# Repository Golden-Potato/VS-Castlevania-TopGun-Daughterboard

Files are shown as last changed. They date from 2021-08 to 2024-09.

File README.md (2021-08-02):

# VS-Castlevania-TopGun-Daughterboard
https://github.com/Golden-Potato/VS-Castlevania-TopGun-Daughterboard

KiCad PCB files to create a reproduction VS Castlevania / VS Topgun daughterboard.  Have it made by your preferred PCB fab. I use http://aisler.net

This design has one minor improvement to avoid bus conflicts that were present on the original Konami design.

The bank switching scheme Konami implemented in the original NES version of Castlevania to address a 128k ROM was dubbed UNROM by the NES emulation community.
https://wiki.nesdev.com/w/index.php/UxROM
It suffered from data bus conflicts during bank switching as the CPU will write data to the bus while the ROM is still writing data to the bus.  Although this conflict was easy to avoid from a hardware standpoint, these game cartridges were to be mass produced, and it was imperative to have as small of a chip count as possible.  Rather than add another IC, Konami got around the conflict by storing the same data in ROM at the addresses being written to by the CPU as the data the CPU was trying to write.  This means that while the CPU and ROM were writing data to the bus at the same time, it was the same data.

This works fine unless the ROM becomes corrupt which can easily happen to the arcade version if programmed on a UV erasable EPROM.  If the data from the ROM and the data being written by the CPU differed, there is a risk of overloading the CPU's data port.

Comparing the original cartridge design with the schematic for VS Topgun daughterboard (located in the manual), it's apparent Konami recycled their design for bank switching the ROM with the exception of some minor changes required for the differences in hardware between the VS system and the NES.  One of the additional ICs present on the VS daughterboard is a quad 2-input NAND gate, and not all of the instances of the IC were used.  This design uses one additional instance of the NAND gate as an inverter to feed the ROM IC's /OE from the CPU's R/W pin which prevents the ROM from writing to the bus when the CPU is writing.

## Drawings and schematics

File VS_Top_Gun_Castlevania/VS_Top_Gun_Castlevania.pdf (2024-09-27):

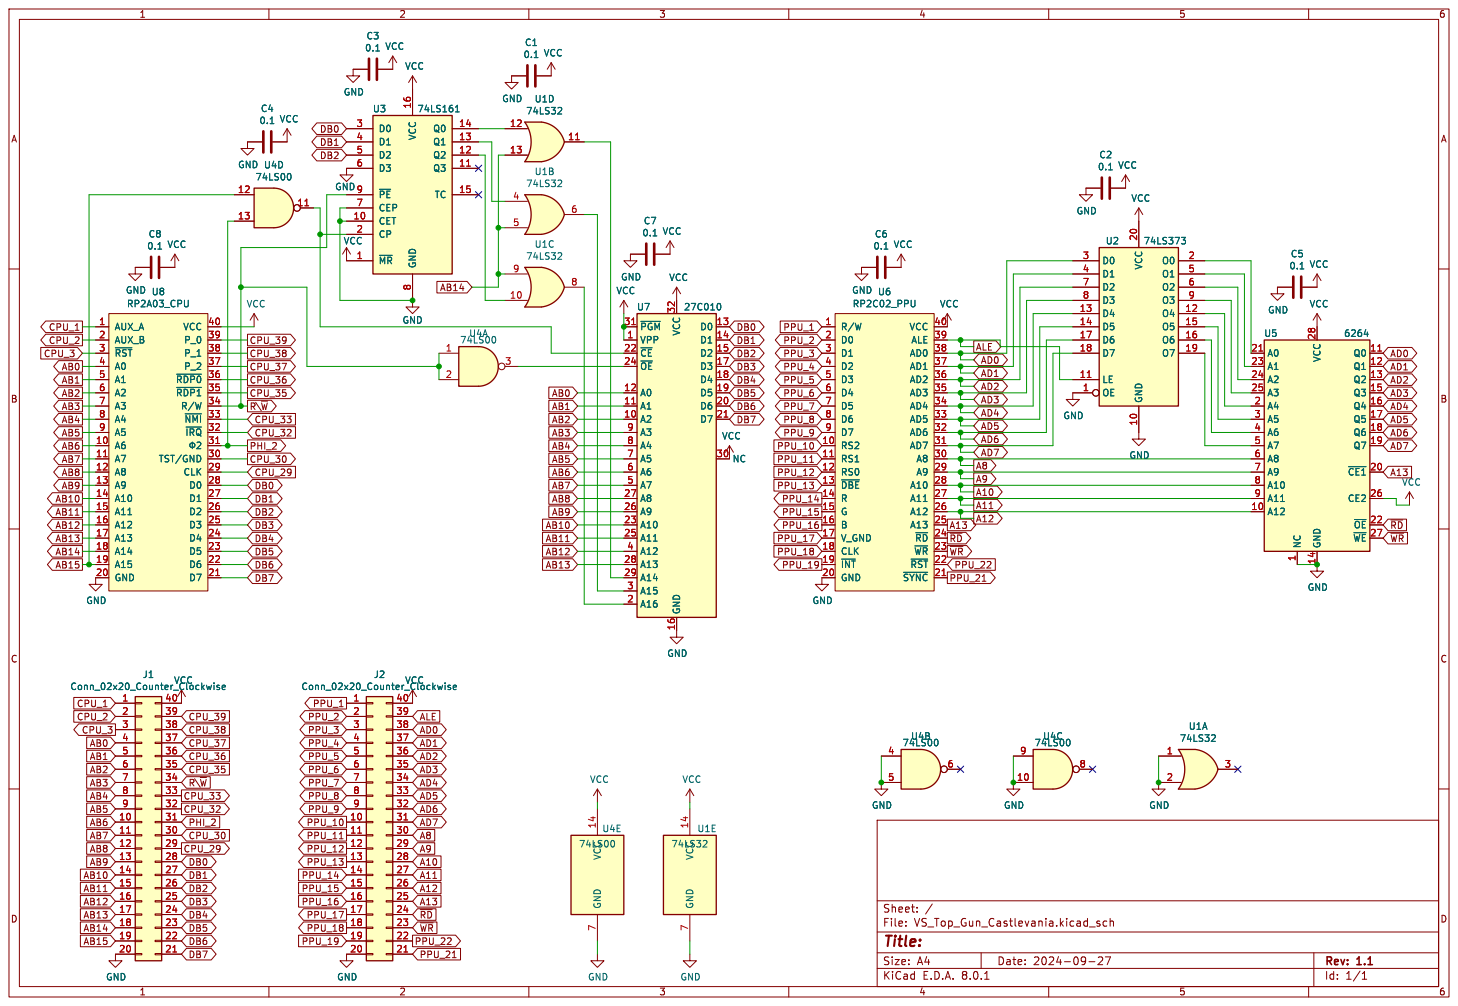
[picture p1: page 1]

1 A12 10 Q0 11 Q1 12 Q2 13 Q3 15 Q4 16 Q5 17 Q6 18 Q7 19 A4 2 ~{CE1}20 A0 21 ~{OE} 22 A1 23 A2 24 A3 25 CE2 26 ~{WE} 27 A5 3 A6 4 A7 5 A8 6 A9 7 A10 8 A11 9 U5 6264 GND GND VCC

VCC GND 14 VCC 28 NC

Id: 1/1 Title: File: VS_Top_Gun_Castlevania.kicad_sch Sheet: /

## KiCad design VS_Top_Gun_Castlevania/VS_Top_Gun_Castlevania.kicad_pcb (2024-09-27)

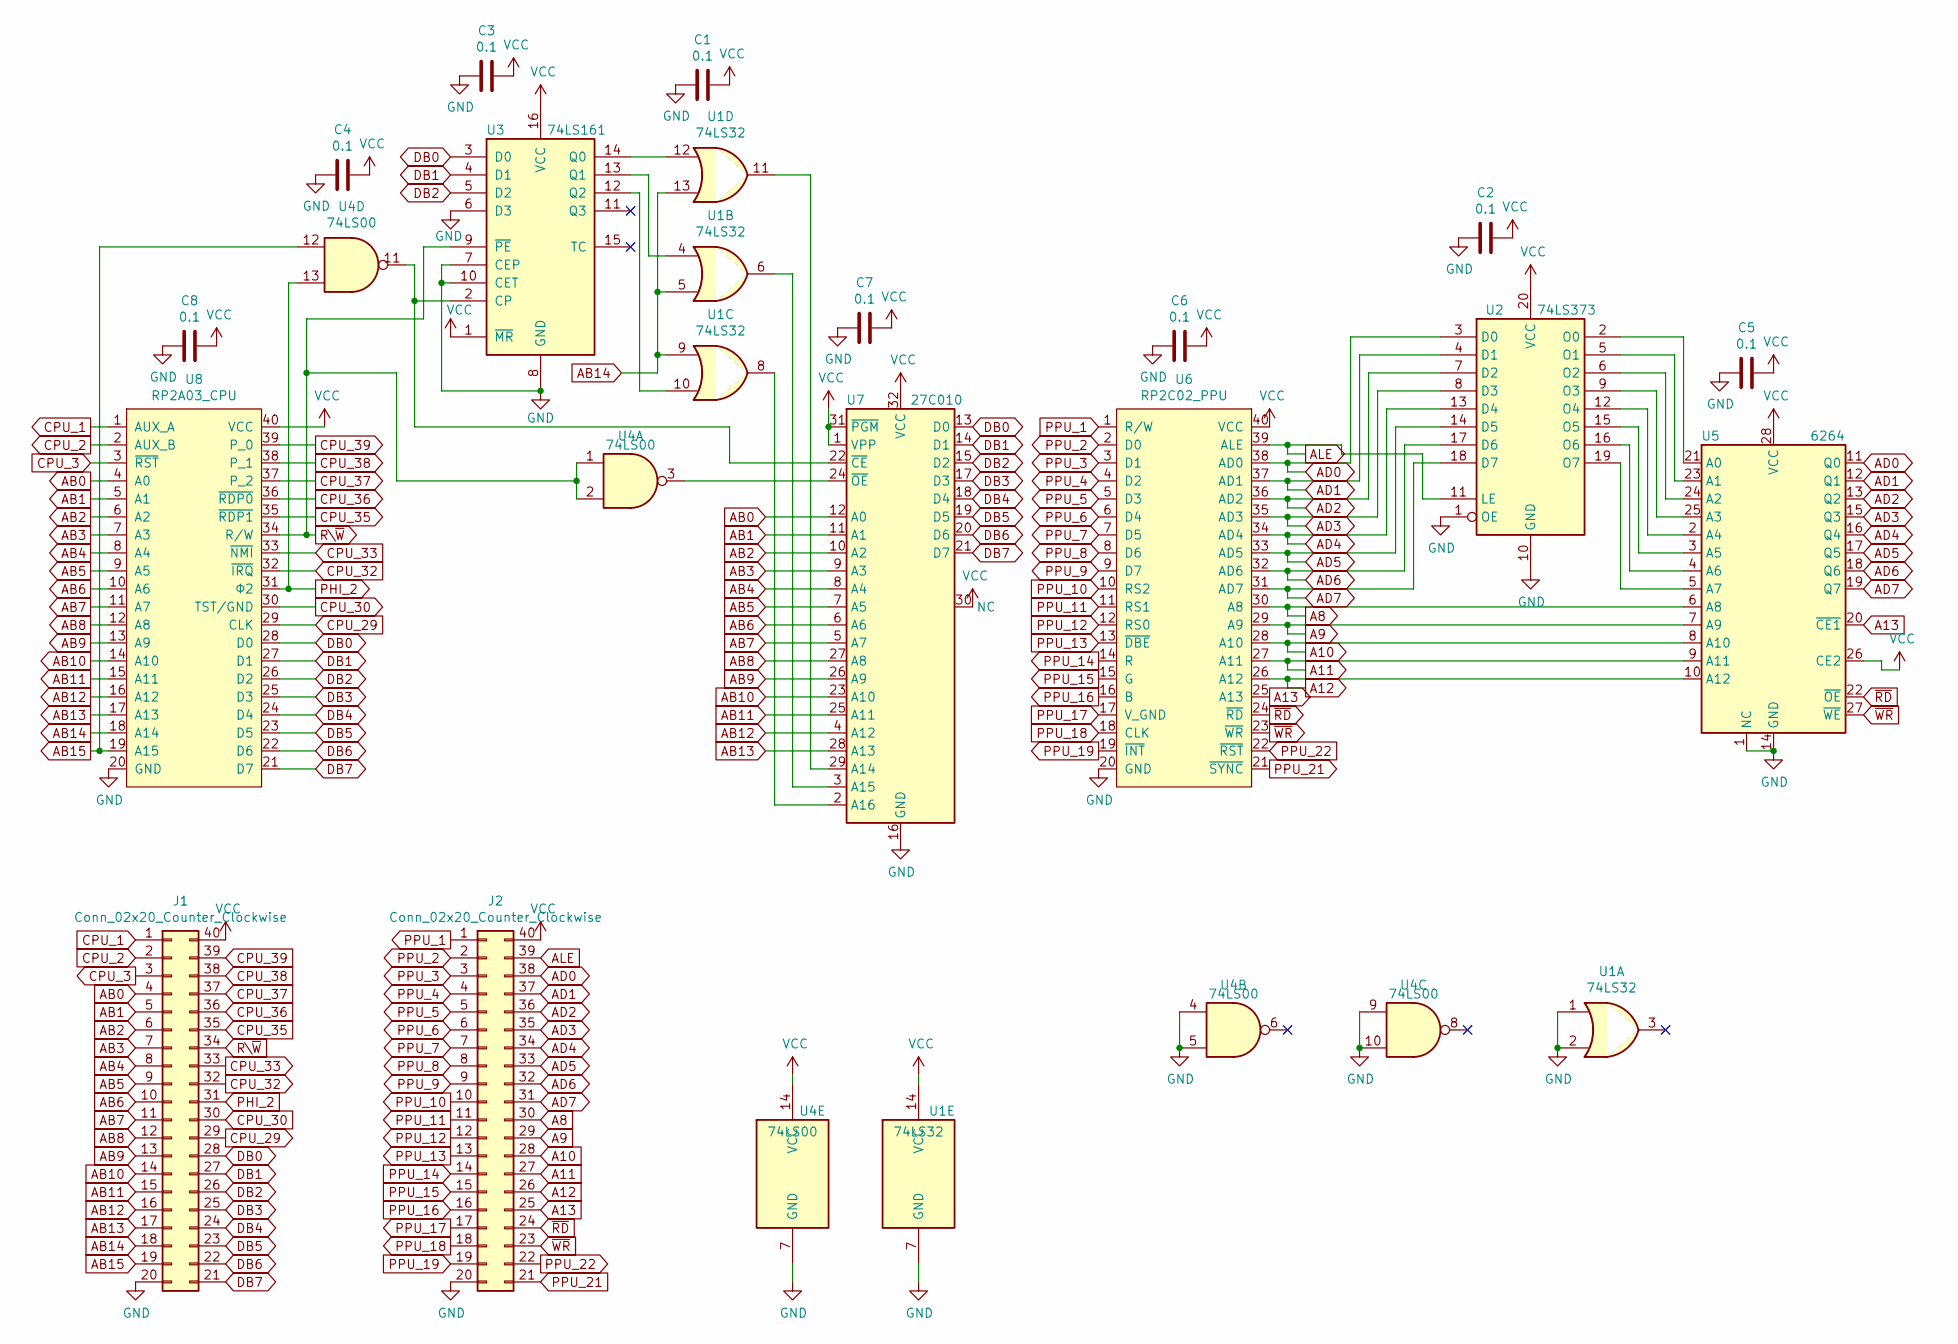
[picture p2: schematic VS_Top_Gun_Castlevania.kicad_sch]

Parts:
C1, C2, C3, C4, C5, C6, C7, C8: 0.1; C_Disc_D12.5mm_W5.0mm_P7.50mm
J1, J2: Conn_02x20_Counter_Clockwise; DIP-40_W15.24mm_Socket
U1: 74LS32; DIP-14_W7.62mm_Socket
U2: 74LS373; DIP-20_W7.62mm_Socket
U3: 74LS161; DIP-16_W7.62mm_Socket
U4: 74LS00; DIP-14_W7.62mm_Socket
U5: 6264; DIP-28_W15.24mm_Socket
U6: RP2C02_PPU; DIP-40_W15.24mm_Socket
U7: 27C010; DIP-32_W15.24mm_Socket
U8: RP2A03_CPU; DIP-40_W15.24mm_Socket

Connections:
A8: J2.30, U5.6 (A8), U6.30 (A8)
A9: J2.29, U5.7 (A9), U6.29 (A9)
A10: J2.28, U5.8 (A10), U6.28 (A10)
A11: J2.27, U5.9 (A11), U6.27 (A11)
A12: J2.26, U5.10 (A12), U6.26 (A12)
A13: J2.25, U5.20 (~CE1), U6.25 (A13)
AB0: J1.4, U7.12 (A0), U8.4 (A0)
AB1: J1.5, U7.11 (A1), U8.5 (A1)
AB2: J1.6, U7.10 (A2), U8.6 (A2)
AB3: J1.7, U7.9 (A3), U8.7 (A3)
AB4: J1.8, U7.8 (A4), U8.8 (A4)
AB5: J1.9, U7.7 (A5), U8.9 (A5)
AB6: J1.10, U7.6 (A6), U8.10 (A6)
AB7: J1.11, U7.5 (A7), U8.11 (A7)
AB8: J1.12, U7.27 (A8), U8.12 (A8)
AB9: J1.13, U7.26 (A9), U8.13 (A9)
AB10: J1.14, U7.23 (A10), U8.14 (A10)
AB11: J1.15, U7.25 (A11), U8.15 (A11)
AB12: J1.16, U7.4 (A12), U8.16 (A12)
AB13: J1.17, U7.28 (A13), U8.17 (A13)
AB14: J1.18, U1.5, U1.9, U1.13, U8.18 (A14)
AB15: J1.19, U4.12, U8.19 (A15)
AD0: J2.38, U2.3 (D0), U5.11 (Q0), U6.38 (AD0)
AD1: J2.37, U2.4 (D1), U5.12 (Q1), U6.37 (AD1)
AD2: J2.36, U2.7 (D2), U5.13 (Q2), U6.36 (AD2)
AD3: J2.35, U2.8 (D3), U5.15 (Q3), U6.35 (AD3)
AD4: J2.34, U2.13 (D4), U5.16 (Q4), U6.34 (AD4)
AD5: J2.33, U2.14 (D5), U5.17 (Q5), U6.33 (AD5)
AD6: J2.32, U2.17 (D6), U5.18 (Q6), U6.32 (AD6)
AD7: J2.31, U2.18 (D7), U5.19 (Q7), U6.31 (AD7)
ALE: J2.39, U2.11 (LE), U6.39 (ALE)
CPU_1: J1.1, U8.1 (AUX_A)
CPU_2: J1.2, U8.2 (AUX_B)
CPU_3: J1.3, U8.3 (~RST)
CPU_29: J1.29, U8.29 (CLK)
CPU_30: J1.30, U8.30 (TST/GND)
CPU_32: J1.32, U8.32 (~IRQ)
CPU_33: J1.33, U8.33 (~NMI)
CPU_35: J1.35, U8.35 (~RDP1)
CPU_36: J1.36, U8.36 (~RDP0)
CPU_37: J1.37, U8.37 (P_2)
CPU_38: J1.38, U8.38 (P_1)
CPU_39: J1.39, U8.39 (P_0)
DB0: J1.28, U3.3 (D0), U7.13 (D0), U8.28 (D0)
DB1: J1.27, U3.4 (D1), U7.14 (D1), U8.27 (D1)
DB2: J1.26, U3.5 (D2), U7.15 (D2), U8.26 (D2)
DB3: J1.25, U7.17 (D3), U8.25 (D3)
DB4: J1.24, U7.18 (D4), U8.24 (D4)
DB5: J1.23, U7.19 (D5), U8.23 (D5)
DB6: J1.22, U7.20 (D6), U8.22 (D6)
DB7: J1.21, U7.21 (D7), U8.21 (D7)
GND: C1.1, C2.1, C3.1, C4.1, C5.1, C6.1, C7.1, C8.1, J1.20, J2.20, U1.1, U1.2, U1.7 (GND), U2.1 (OE), U2.10 (GND), U3.6 (D3), U3.7 (CEP), U3.8 (GND), U3.10 (CET), U4.4, U4.5, U4.7 (GND), U4.9, U4.10, U5.1 (NC), U5.14 (GND), U6.20 (GND), U7.16 (GND), U8.20 (GND)
unnamed: U2.2 (O0), U5.21 (A0)
unnamed: U2.5 (O1), U5.23 (A1)
unnamed: U2.6 (O2), U5.24 (A2)
unnamed: U2.9 (O3), U5.25 (A3)
unnamed: U2.12 (O4), U5.2 (A4)
unnamed: U2.15 (O5), U5.3 (A5)
unnamed: U2.16 (O6), U5.4 (A6)
unnamed: U2.19 (O7), U5.5 (A7)
unnamed: U3.2 (CP), U4.11, U7.22 (~CE)
unnamed: U1.12, U3.14 (Q0)
unnamed: U1.4, U3.13 (Q1)
unnamed: U1.10, U3.12 (Q2)
unnamed: U1.11, U7.29 (A14)
unnamed: U1.6, U7.3 (A15)
unnamed: U1.8, U7.2 (A16)
unnamed: U4.3, U7.24 (~OE)
PHI_2: J1.31, U4.13, U8.31 (Φ2)
PPU_1: J2.1, U6.1 (R/W)
PPU_2: J2.2, U6.2 (D0)
PPU_3: J2.3, U6.3 (D1)
PPU_4: J2.4, U6.4 (D2)
PPU_5: J2.5, U6.5 (D3)
PPU_6: J2.6, U6.6 (D4)
PPU_7: J2.7, U6.7 (D5)
PPU_8: J2.8, U6.8 (D6)
PPU_9: J2.9, U6.9 (D7)
PPU_10: J2.10, U6.10 (RS2)
PPU_11: J2.11, U6.11 (RS1)
PPU_12: J2.12, U6.12 (RS0)
PPU_13: J2.13, U6.13 (~DBE)
PPU_14: J2.14, U6.14 (R)
PPU_15: J2.15, U6.15 (G)
PPU_16: J2.16, U6.16 (B)
PPU_17: J2.17, U6.17 (V_GND)
PPU_18: J2.18, U6.18 (CLK)
PPU_19: J2.19, U6.19 (~INT)
PPU_21: J2.21, U6.21 (~SYNC)
PPU_22: J2.22, U6.22 (~RST)
R\~W: J1.34, U3.9 (~PE), U4.1, U4.2, U8.34 (R/W)
VCC: C1.2, C2.2, C3.2, C4.2, C5.2, C6.2, C7.2, C8.2, J1.40, J2.40, U1.14 (VCC), U2.20 (VCC), U3.1 (~MR), U3.16 (VCC), U4.14 (VCC), U5.26 (CE2), U5.28 (VCC), U6.40 (VCC), U7.1 (VPP), U7.31 (~PGM), U7.32 (VCC), U8.40 (VCC)
~RD: J2.24, U5.22 (~OE), U6.24 (~RD)
~WR: J2.23, U5.27 (~WE), U6.23 (~WR)

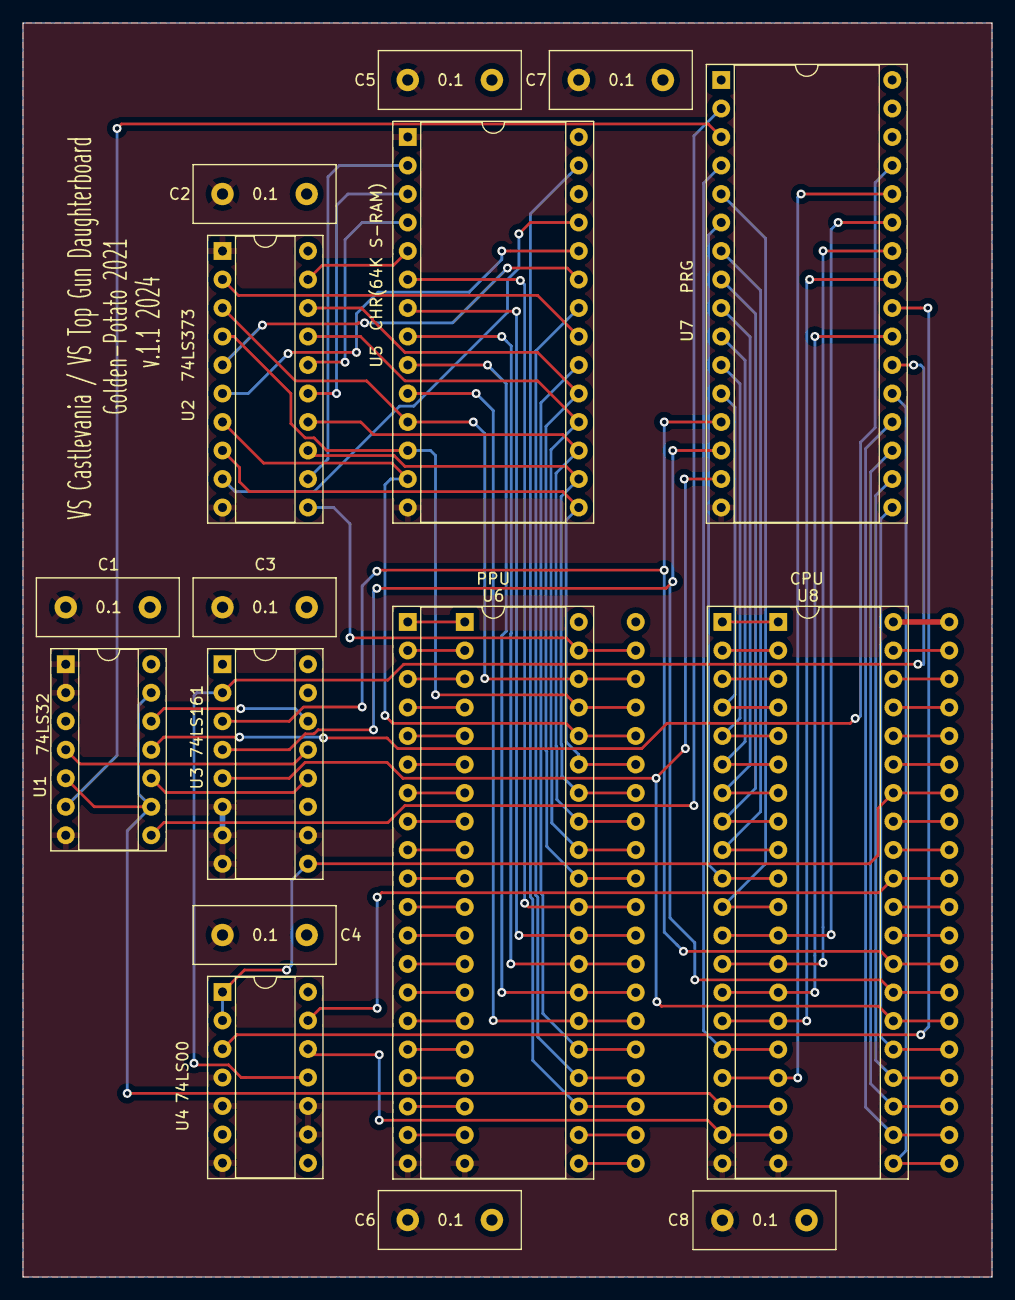
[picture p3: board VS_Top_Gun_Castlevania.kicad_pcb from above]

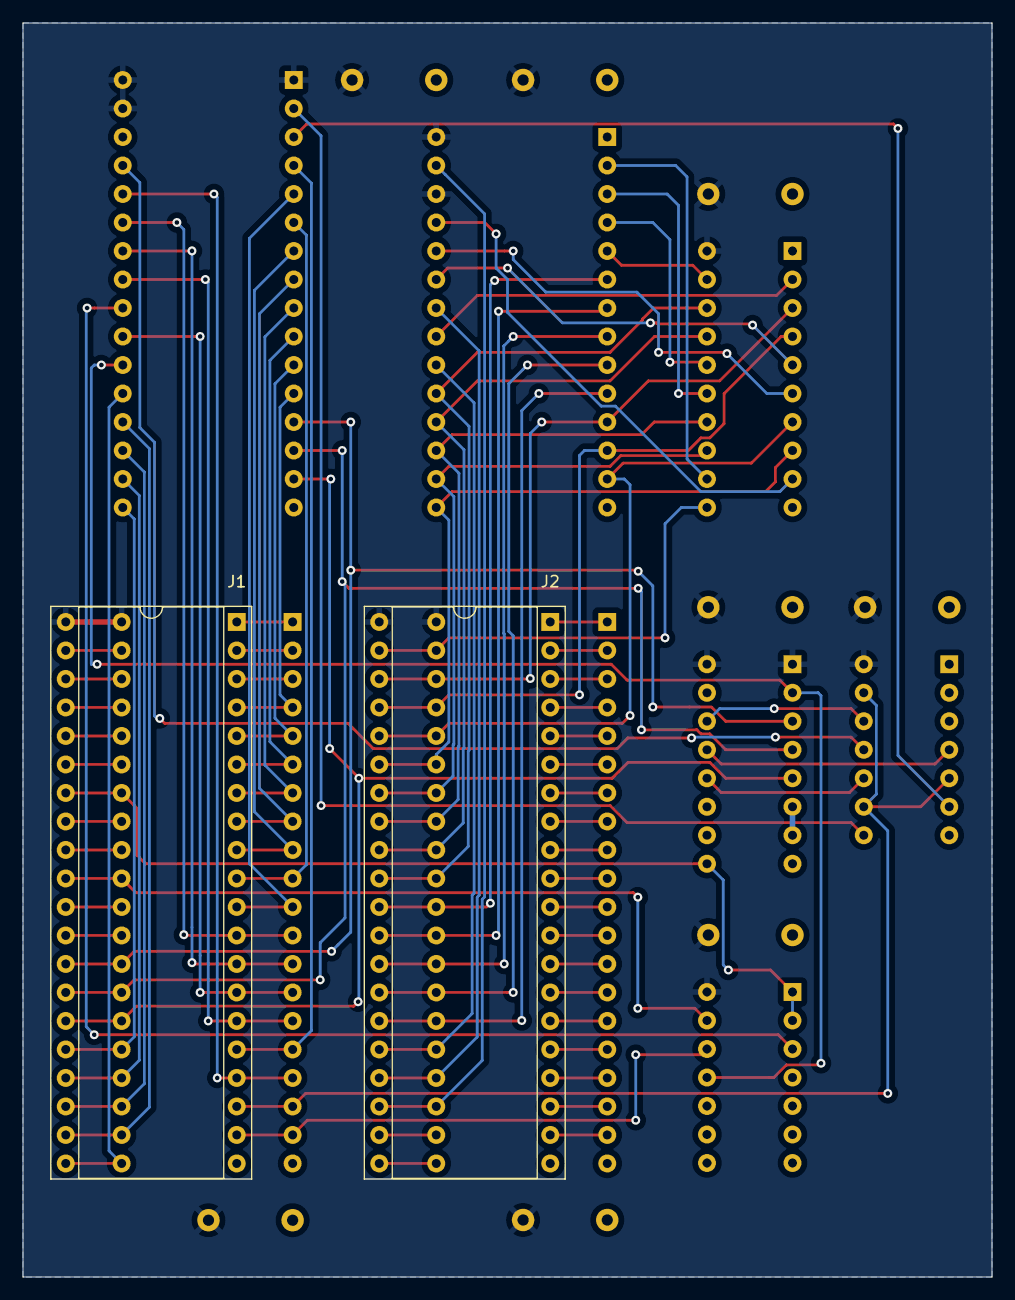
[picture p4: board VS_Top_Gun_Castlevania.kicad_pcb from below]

Board: 2 copper layers, 86.4 x 111.8 mm, 18 parts (2 on the bottom side), 94 nets.
